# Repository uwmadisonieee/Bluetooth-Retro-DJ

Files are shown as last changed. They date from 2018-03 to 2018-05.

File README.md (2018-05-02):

# Bluetooth Retro DJ

This is a IEEE project designed to grab all the attention at every table event. Using the power of ECE majors we contructed the ultimate Retro DJ set that communicates between bluetooth.

<p align="center">
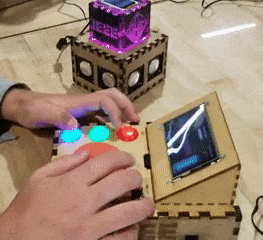
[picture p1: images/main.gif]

</p>

## How It All Works!

For details on this, check out either the [Medium Article](https://medium.com/@spencerfricke/bluetooth-dj-set-diy-embedded-systems-d240a5f08773), [short YouTube Video of it](https://youtu.be/4wVTRmy3RTk), or feel free to glance around the code.

## MIDI Controller Box

<p align="center">
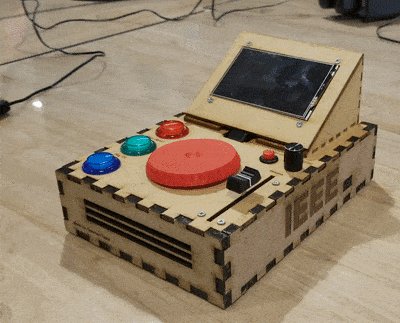
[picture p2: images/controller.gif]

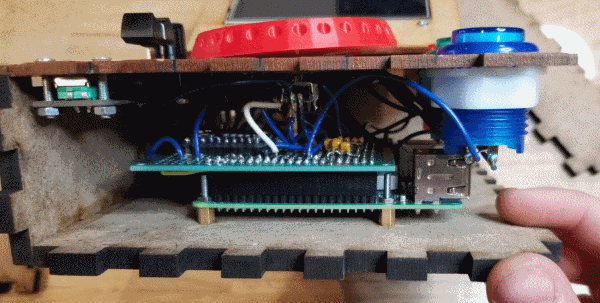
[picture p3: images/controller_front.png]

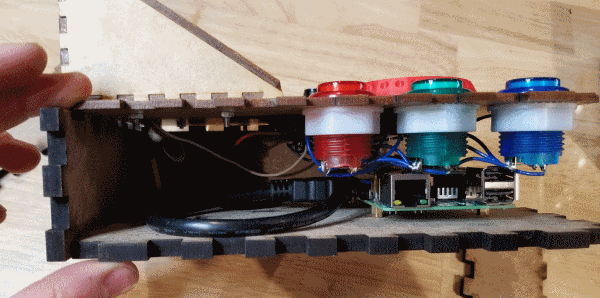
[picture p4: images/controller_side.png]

</p>

## LED Speaker

<p align="center">
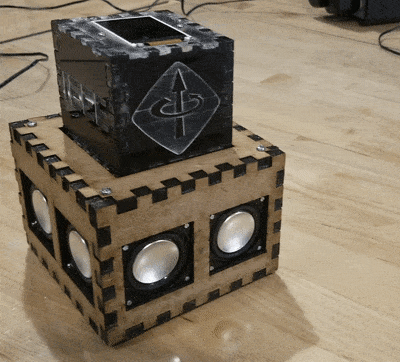
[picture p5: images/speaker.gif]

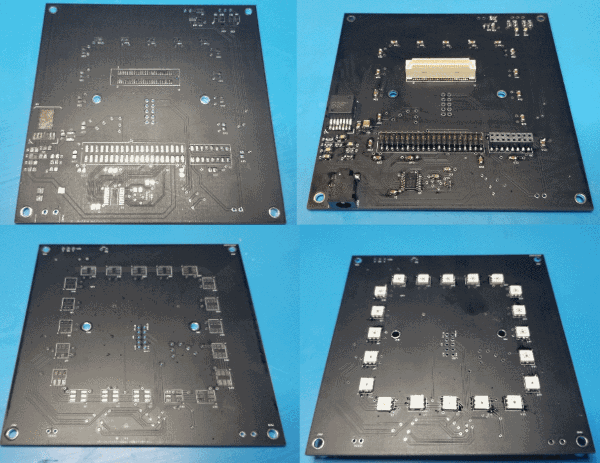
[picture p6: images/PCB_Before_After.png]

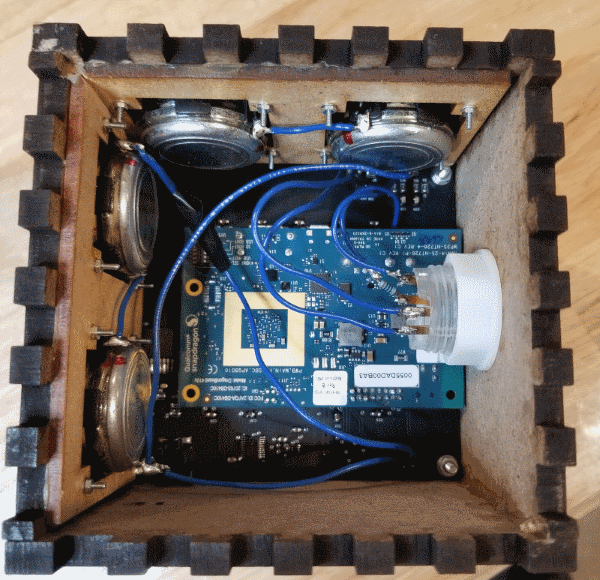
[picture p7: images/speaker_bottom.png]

</p>

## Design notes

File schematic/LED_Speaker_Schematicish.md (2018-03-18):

# LED Speaker Schematics*ish*

> "Sorry Max, I should have learned how to use Altium" ~ Spencer 2018

**Table of Contents**

- [PCB](#pcb)
  - [Basic Layout Concept](#basic-layout-concept)
  - [Dragonboard](#dragonboard)
  - [Power](#power)
  - [Standoff Holes](#standoff-holes)
- [Dragonboard GPIO](#dragonboard-gpio)
- [APA102 LEDS](#apa102-leds)
  - [Layout](#layout)
  - [Pins](#pins)
- [LCD Screen](#lcd-screen)
  - [Pins needed](#pins-needed)
- [Rotary Encoder and Button](#rotary-encoder-and-button)
- [Speakers](#speakers)

# PCB

**Dimensions:** 100mm x 100mm

[Blender File](https://github.com/uwmadisonieee/Bluetooth-Retro-DJ/raw/master/3D_Models/LED_Speaker/LED_Speaker.blend)

## Basic Layout Concept
- 20 LEDs
- Standoffs for inside and out for structural support
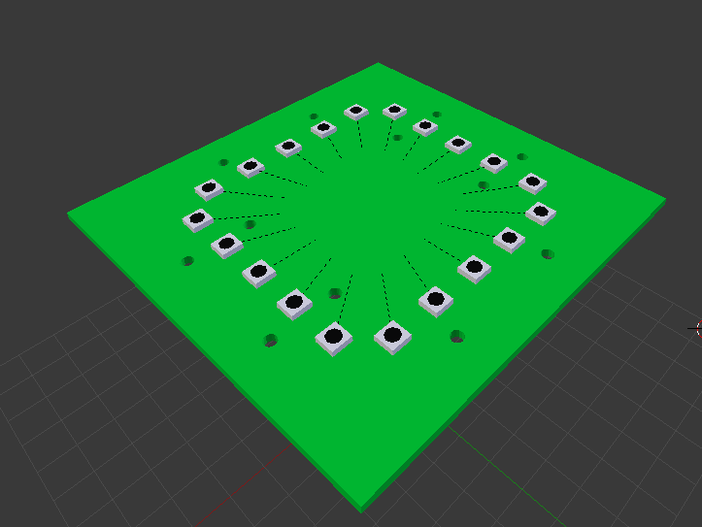
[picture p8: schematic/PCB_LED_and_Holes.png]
- 

## Dragonboard
- Attached from under via Low and High speed connectors (same as Truman)
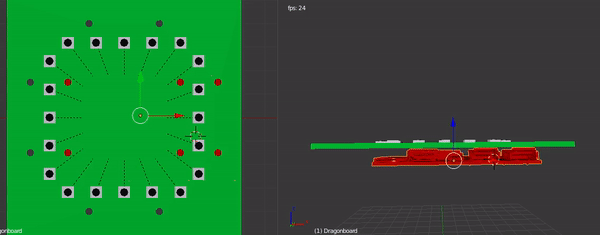
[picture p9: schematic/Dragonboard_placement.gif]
- 
- 
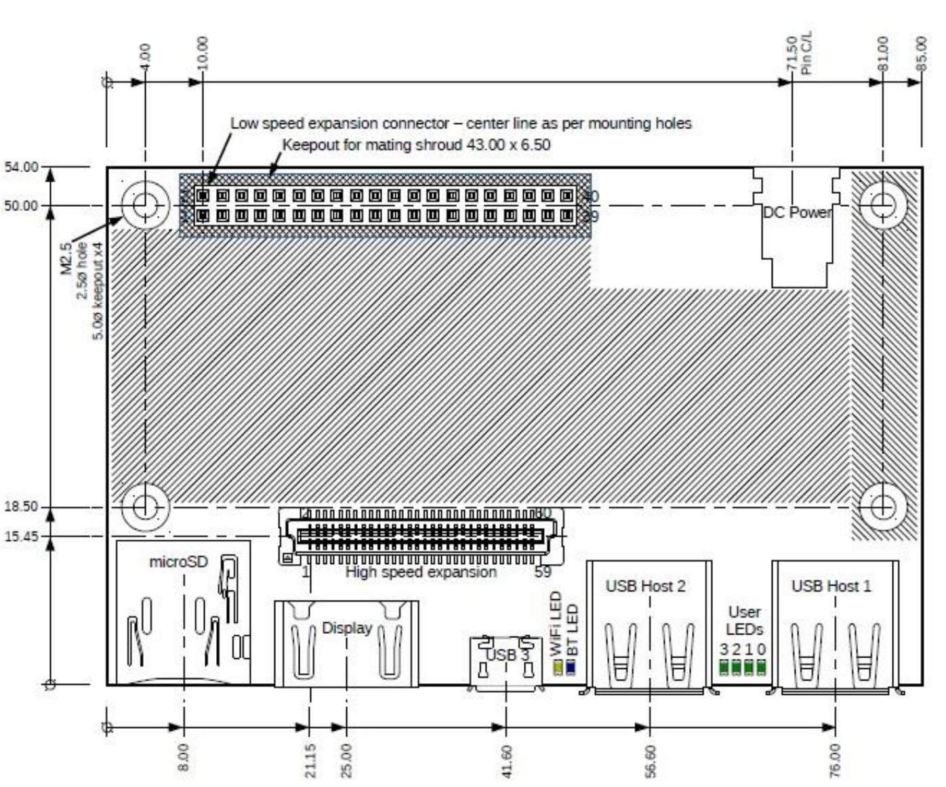
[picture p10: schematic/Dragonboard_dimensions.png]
- 
	
## Power

- Barrel Jack on edge of PCB
	- On bottom side
	- Which side is not a concern
- EIAJ3 plug which has 4.75mm diameter with 1.7mm inner diameter
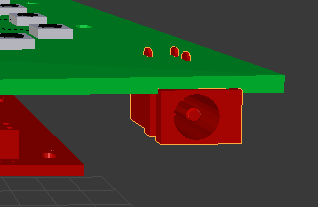
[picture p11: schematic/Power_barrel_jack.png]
- 

## Standoff Holes
- All Standoff holes are M3 so 3mm diameter holes
- I need to mount the PCB to the base wood box with the outer holes
	- These honestly can be **anywhere**, the closer to the edge would be best for structural support I think
- The inner standoffs are going to be mounted to a pole mounted to top cube
	- These need to be a little more aimed because there is a LED screen on top
	- There is a **12.325mm x 58.65mm** box on each side for two standoff holes
- 

# Dragonboard GPIO
- [Hardware Docs](https://github.com/96boards/documentation/tree/master/consumer/dragonboard410c/hardware-docs)
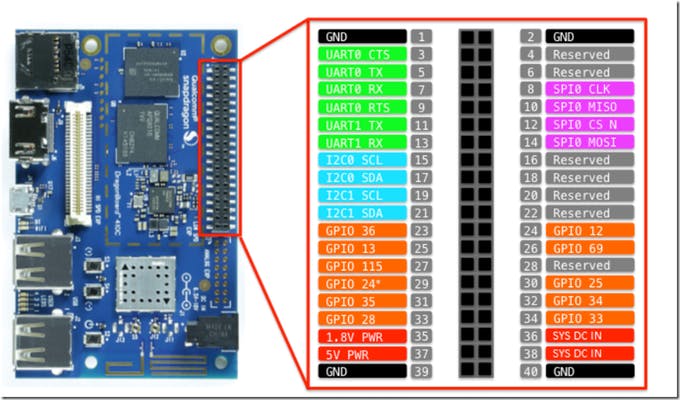
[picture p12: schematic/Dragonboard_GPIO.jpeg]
- 
- **PIN 8** - SPI Clk for LED and LCD
- **PIN 14** - SPI MOSI for LED and LCD
- **PIN 24** - SPI Clock Select pin to control Mux for LED and LCD
	- **LOW** turns on LCD
	- **HIGH** turns on LED
- **PIN 26** - Reset Pin for LCD 
- **PIN 31** - Data/Control pin for LCD
- **PIN 32** - Rotary Encoder A
- **PIN 34** - Rotary Encoder B
- **PIN 33** - Push Button

# APA102 LEDS
- [Datasheet](https://cdn.sparkfun.com/datasheets/Components/LED/APA102C.pdf)
- 5mm x 5mm x 1.4mm 
	- [8 long example datasheet](https://cdn.sparkfun.com/assets/d/e/9/0/e/Lumenati_8-stick.pdf) 
		- [Eagle Files](https://github.com/sparkfun/Lumenati_8-Stick/tree/master/Hardware)
	- [1 meter strip example datasheet](https://cdn.sparkfun.com/datasheets/Components/LED/S60102.pdf) 

- 20 LEDs on PCB all in series
- Draws ~1.92A at full white light

## Layout
- 
- All LEDs in each strip are 31.825mm from center in X or Y direction
- All LEDs are 18.175mm from edge
- Each LED is 12mm apart from center to center
	- This starts with the middle LED at center in row

## Pins
- Each has 6 pins
	- Data In
	- Clock In
	- GND
	- Data Out
	- Clock Out
	- VCC
- **VCC and GND**
	- This is ran on a 5V rail from main power source because LEDs current draw too much for Dragonboard
- **Data In**
	- The first LED in series is sent data from **PIN 14** of Dragonboard **stepped up to 5V**
- **Clock In**
	- The first LED in series is sent clock from **PIN 8** of Dragonboard **stepped up to 5V**	
- **Clock Select**
	- The first LED in series is clock select via a mux on PCB from **PIN 24** of Dragonboard
	- The APA102 LED only takes SPI feed and has be muxed so SPI can be used in LCD screen as well

# LCD Screen
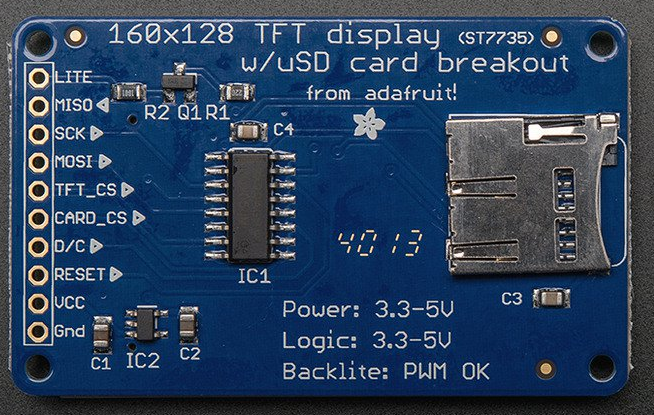
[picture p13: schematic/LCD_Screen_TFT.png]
- 
- This screen will be on top of cube so through holes needed to soilder wires
	- **DONT WORRY** Inside of acrylic is going to be painted black so no one will see wires
- All pins **stepped up to 5V**
- Holes must be in inner part of LED ring

## Pins needed
- **LITE and VCC** - This is a 5V power line
- **GND**
- **SCK** --- **PIN 8** of Dragonboard for SPI CLK
- **MOSI** --- **PIN 14** of Dragonboard for SPI MOSI
- **RESET** --- **PIN 28** of Dragonboard
- **D/C** (Data/Control) --- **PIN 30** of Dragonboard
- **TFT_CS** --- **PIN 24** of Dragonboard is used to toggle between LED and LCD screen, this is the pin to toggle for LCD Screen

# Rotary Encoder and Button
- I am going to have these coming out from a side of speaker box
- Need through hole of **PIN 32**, **PIN 33**, and **PIN 34** for controlling these
- Not same side as power barell jack
- Holes will need to be accessed from bottom so best to use edge where Dragonboard isn't sticking out

# Speakers
- We **only need the 2** pins on the edge nearest to the 40 pin set (pin 1 and 2)
	- I will need 2 through hole pins to wire up the Speakers underneath
	- Same idea as Encoder and Button where to put near on a side where Dragonboard isn't sticking out
- [Datasheet for Dragonboard Audio](https://developer.qualcomm.com/qfile/29468/lm80-p0436-43_stereocontaudioroutappnote.pdf)
- What the Audio Mezz does
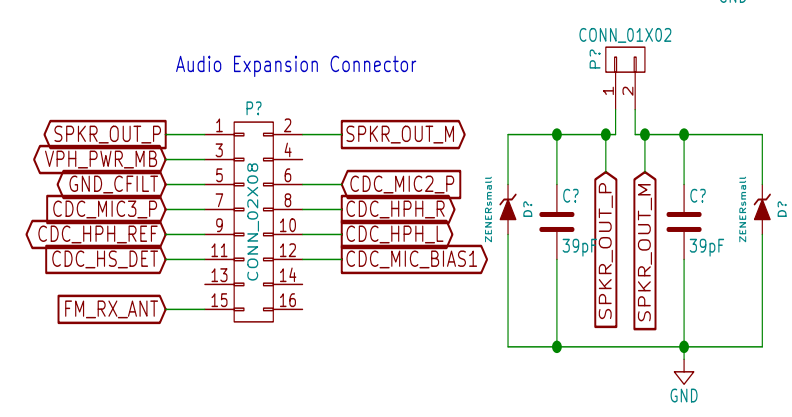
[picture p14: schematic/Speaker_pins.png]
	- 
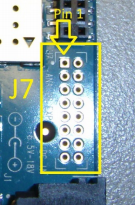
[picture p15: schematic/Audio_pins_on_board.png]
- 
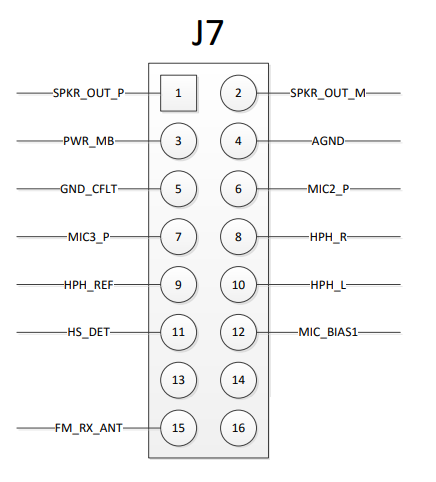
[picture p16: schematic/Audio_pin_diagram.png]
-

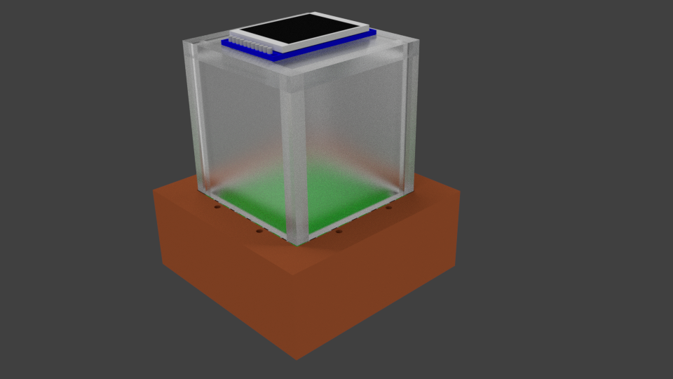
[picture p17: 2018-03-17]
3D_Models/LED_Speaker/LED_Concept.png

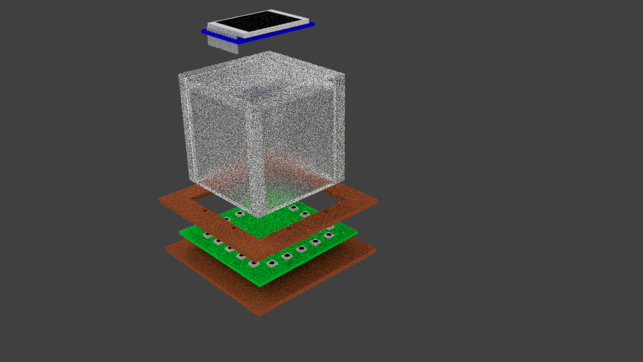
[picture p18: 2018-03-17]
3D_Models/LED_Speaker/LED_Concept_stretched.png

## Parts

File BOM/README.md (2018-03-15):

# Bill of materials

This isn't a true BOM, but more of a checklist that I order everything I need for this project

- [MIDI Controller Box](MIDI_Controller_Box_BOM.md)

- [LED Speaker](LED_Speaker_BOM.md)

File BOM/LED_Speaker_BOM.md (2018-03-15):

# LED Speaker BOM

- Dragonboard
- 128x160 TFT LED Screen
- Custon PCB with LEDs on it
- Rotatry Encoder
- Button
- Set of Speakers
- Protoboard
- Standoffs
- 3.3v to 5v chips
- PCB design
	- TBD

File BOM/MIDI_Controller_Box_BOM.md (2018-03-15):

# MIDI Controller Box BOM

- Pi
- rotary encoder
- 3D printed jog wheel
- potentiometer slider
- (3) LED arcade buttons
- (2) dial potentiometer
- 4 inch HDMI screen
- HDMI cable (short)
- Protoboard
- Standoffs
- microUSB outlet to wires
- ADC Module
- 3.3v to 5v chips

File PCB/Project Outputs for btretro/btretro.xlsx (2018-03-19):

Comment | Description | Designator | LibRef | Manufacturer 1 | Quantity | Supplier 1 | Supplier Part Number 1
CAP_0805_.1u_250V | Cap Ceramic 0.1uF 250V X7T 10% SMD 0805 125C Plastic T/R | C1, C2, C11, C12, C13, C14, C15, C16, C17, C18, C19, C20, C21, C22, C23, C24, C25, C26, C27, C28, C29, C30, C31 | CAP_0805_.1u_250V | TDK | 23 | Digi-Key | 445-8883-1-ND
CAP_0805_m22n | CAP CER 0.022UF 100V X7R 0805 | C5, C10 | CAP_0805_22n_100V | TDK | 2 | Digi-Key | 445-9184-1-ND
CAP_0805_10u_16V | Cap Ceramic 10uF 16V X5R 10% SMD 0805 85C T/R | C6 | CAP_0805_10u_16V | Johanson | 1 | Digi-Key | 709-1229-1-ND
CAP_1210_100u_10V | Cap Ceramic 100uF 10V X5R 20% SMD 1210 85C Embossed T/R | C7 | CAP_1210_100u_10V | Murata | 1 | Digi-Key | 490-9969-1-ND
CAP_0805_1u_100V | CAP CER 1UF 100V X7S 0805 | C8 | CAP_0805_1u_100V | TDK | 1 | Digi-Key | 445-8887-1-ND
CAP_0805_22u_25V | 22µF ±20% 25V X5R Ceramic Capacitor -55°C ~ 85°C Surface Mount, MLCC 0805 (2012 Metric) 0.079" L x 0.049" W (2.00mm x 1.25mm) | C9 | CAP_0805_22u_25V | Samsung | 1 | Digi-Key | 1276-2908-1-ND
CAP_0805_10n_250V | Cap Ceramic 0.1uF 250V X7T 10% SMD 0805 125C Plastic T/R | C32, C33 | CAP_0805_10n_250V | TDK | 2 | Digi-Key | 445-2280-1-ND
DragonBoard_HIGH_SPEED | 60 Position Connector Plug, Center Strip Contacts Surface Mount Gold | J1 | DragonBoard_HIGH_SPEED | Amphenol FCI | 1 | Digi-Key | 609-1681-1-ND
DragonBoard_LOW_SPEED | 40 Positions Header, Unshrouded Connector 0.079" (2.00mm) Surface Mount Gold, GXT™ | J2 | DragonBoard_LOW_SPEED | Amphenol FCI | 1 | Digi-Key | 609-2632-ND
DragonBoard_ANALOG | Conn Socket Strip RCP 16 POS 2mm Solder ST SMD Tube | J3 | DragonBoard_ANALOG | Molex | 1 | Digi-Key | WM18703-ND
Display | TFT Display | LCD1 | LCD_SCREEN_BTRETRO |  | 1
MOUNTHOLES | HOLE | MH1, MH2, MH5, MH6, MH7, MH8 | MOUNTHOLES |  | 6
EIAJ3 | PJ1-021 Series 1.65 mm x 5.15 mm 16 V Right Angle SMT Power Jack | PWR1 | EIAJ3 | CUI | 1 | Digi-Key | CP1-021PJCT-ND
RES_5.23K | Thick Film Resistors 5.23K OHM 1% | R2 | RES_0805_5.23K | Yageo | 1 | Digi-Key | 311-5.23KCRCT-ND
RES_0805_1K | RES SMD 1K OHM 1% 1/8W 0805 | R3 | RES_0805_1K | Yageo Phycomp | 1 | Digi-Key | 311-1.00KCRCT-ND
RES_0805_23.2K | RESISTOR, THICK FILM, 23.2KOHM, 125mW, ± 1% | R4 | RES_0805_23.2K | Panasonic ECG | 1 | Digi-Key | P23.2KCCT-ND
RES_0805_100K | Res Thick Film 0805 100K Ohm 1% 0.125W(1/8W) ±100ppm/C Molded SMD Automotive Punched T/R | R5 | RES_0805_100K | Panasonic ECG | 1 | Digi-Key | P100KCCT-ND
RES_0805_11.8K | RES SMD 11.8K OHM 1% 1/8W 0805 | R6 | RES_0805_11.8K | Yageo | 1 | Digi-Key | 311-11.8KCRCT-ND
RES_0805_10K | RES, THICK FILM, 10K, 5%, 0.125W, 0805 | R7, R8, R9, R10, R11 | RES_0805_10K | Yageo | 5 | Digi-Key | 311-10KARCT-ND
ROT_ENCODER | Encoders 15mm SHAFT w/SWITCH | ROT1 | ROT_ENCODER | Bourns | 1 | Digi-Key | PEC11R-4015F-S0024-ND
CDS-27204-L100 | 4 Ohm Magnetic Speaker 2W 20Hz ~ 20kHz Top Rectangular 93dB | SPKR1 | CDS-27204-L100 | CUI (https://octopart-clicks.com/click/altium?sku=277-1667-ND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) | 1 | Digi-Key | 102-3547-ND (https://octopart-clicks.com/click/altium?sku=277-1667-ND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)
BUTTON | ...It's a button! | SW1 | BUTTON |  | 1
TXS0108 | TRANSLATOR, VOLTAGE, 8BIT, 20TSSOP | U1 | TXS0108 | Texas Instruments | 1 | Digi-Key | 296-23011-1-ND
LMZ12003 | POWER MODULE, TO-PMOD-7, FULL REEL | U2 | LMZ12003 | TI National Semiconductor | 1 | Digi-Key | LMZ12003TZ-ADJ/NOPBCT-ND
APA102c | SPI LED | U3, U4, U5, U6, U7, U8, U9, U10, U11, U12, U13, U14, U15, U16, U17, U18, U19, U20, U21, U22 | APA102 |  | 20
SN74LVC1G17 | IC BUFFER SCHMIT TRIG SOT23-5 | U23 | SN74LVC1G17 | Texas Instruments | 1 | Digi-Key | 296-11933-1-ND
NC7SZ167 | FAIRCHILD SEMICONDUCTOR NC7SZ157P6X Logic Type:Multiplexer | U24 | NC7SZ157 | ON Semiconductor | 1 | Digi-Key | NC7SZ157P6XCT-ND

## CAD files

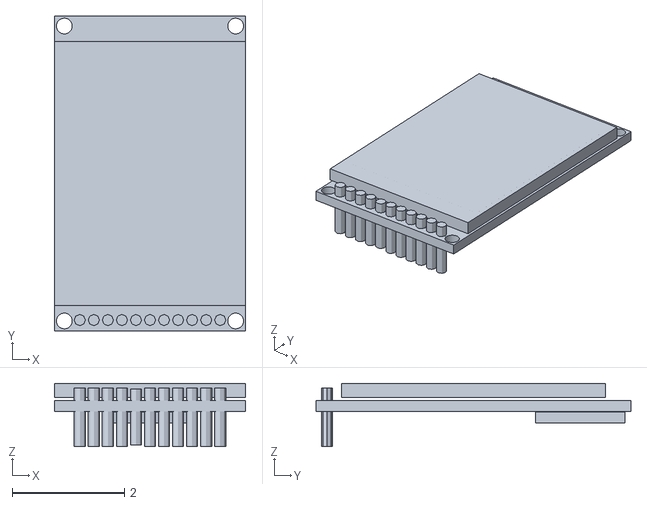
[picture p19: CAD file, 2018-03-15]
3D_Models/LED_Speaker/1-8inch_TFT_Color_LCD.stl
3.40 x 5.60 x 1.13

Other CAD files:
3D_Models/LED_Speaker/1-8inch_TFT_Color_LCD.blend
3D_Models/MIDI_Controller_Box/Controller_Box.blend

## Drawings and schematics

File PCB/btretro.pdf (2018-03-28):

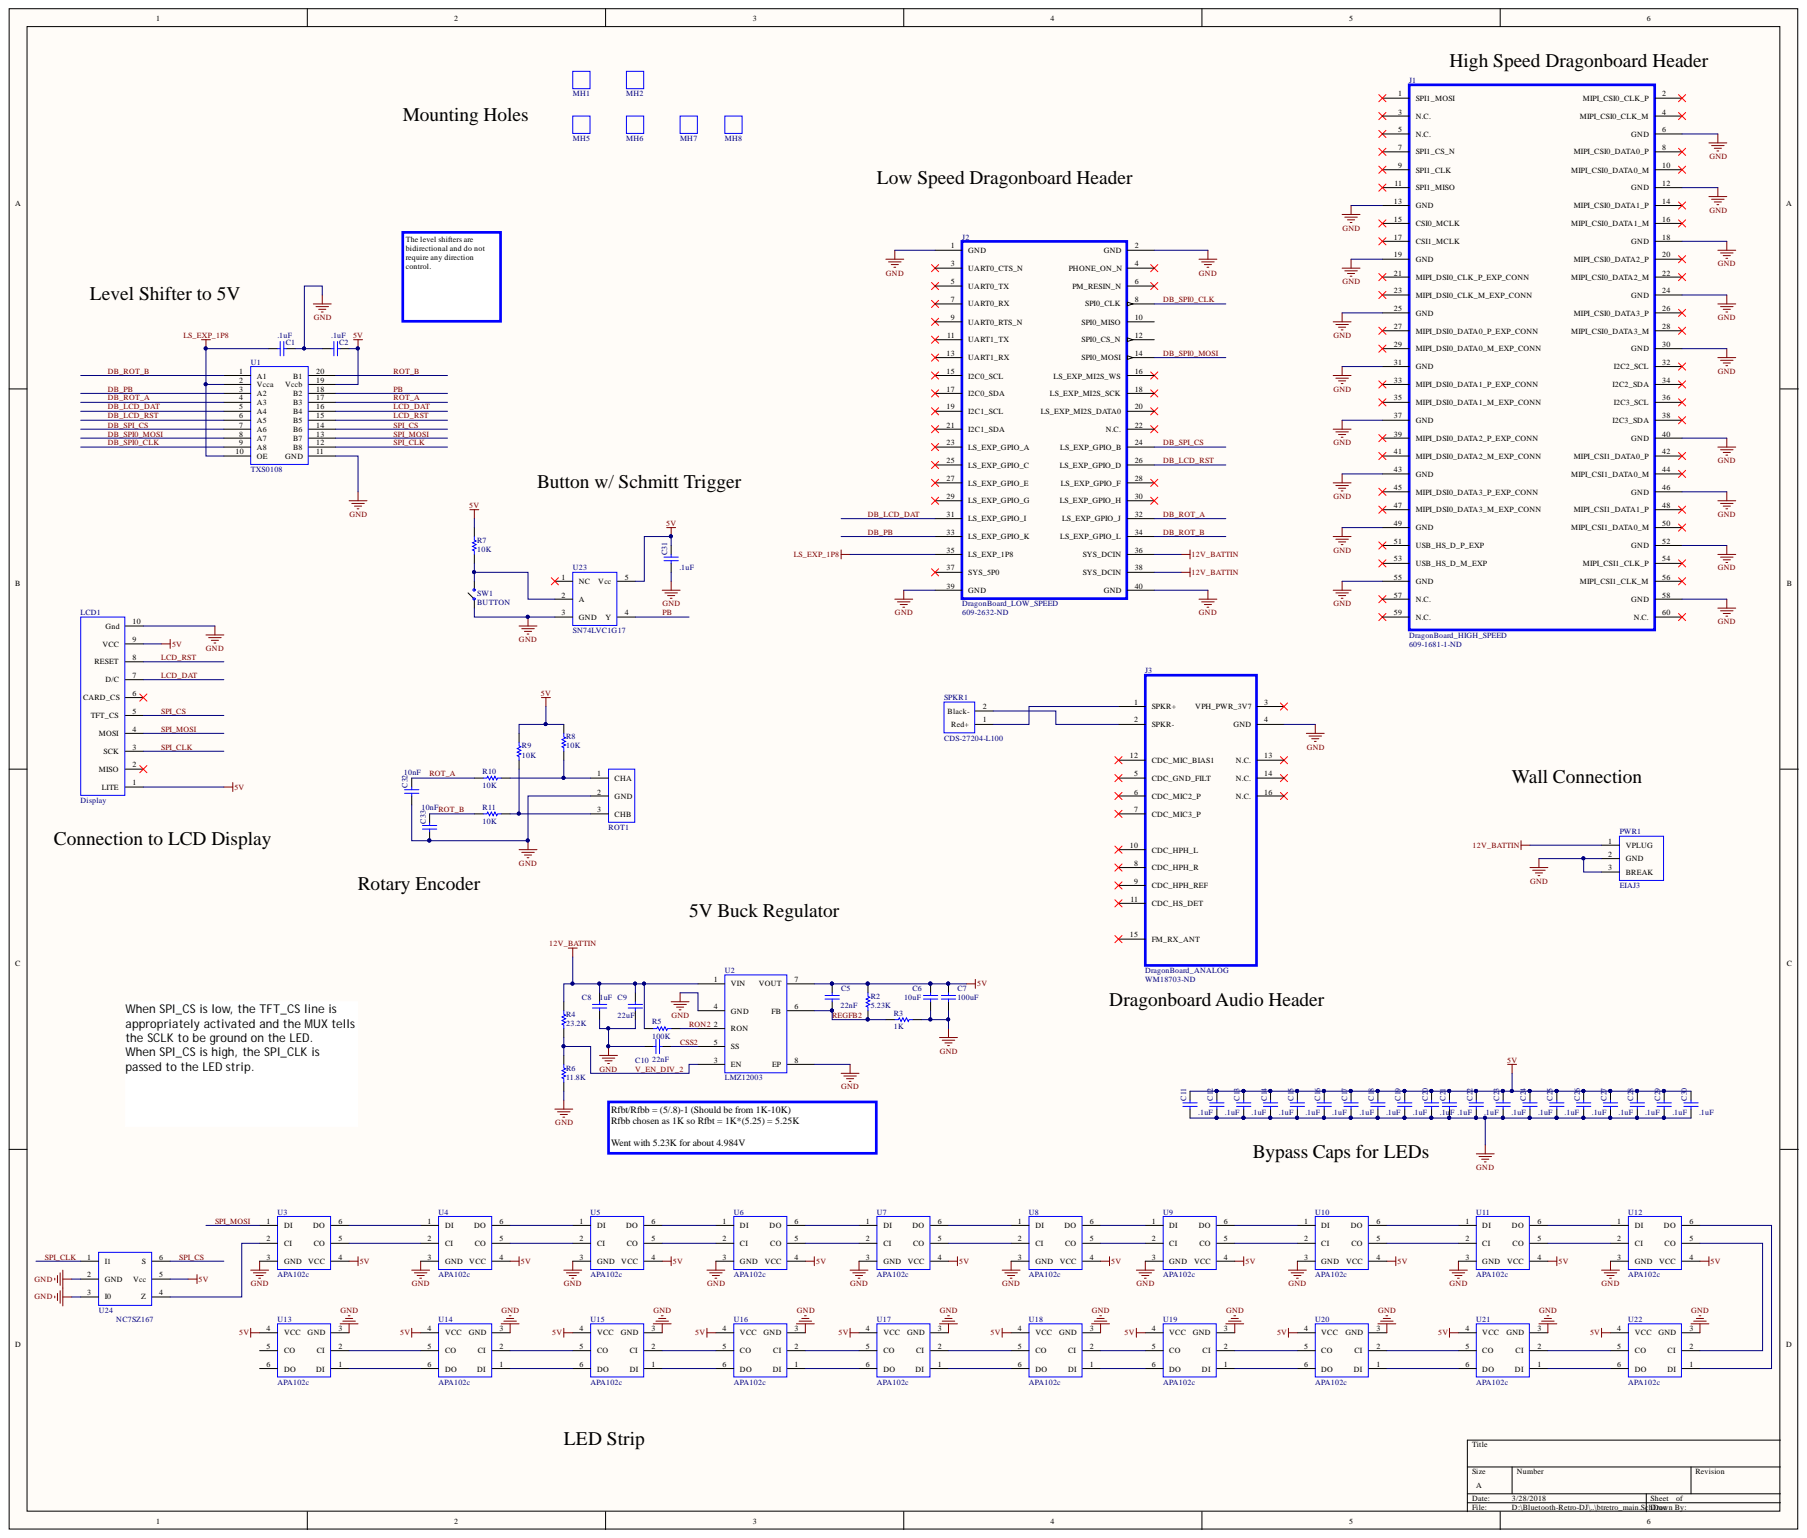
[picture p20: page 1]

High Speed Dragonboard Header

Low Speed Dragonboard Header

The level shifters are
bidirectional and do not
require any direction
control.

Connection to LCD Display

When SPI_CS is low, the TFT_CS line is
appropriately activated and the MUX tells
the SCLK to be ground on the LED.
When SPI_CS is high, the SPI_CLK is
passed to the LED strip.

Rfbt/Rfbb = (5/.8)-1 (Should be from 1K-10K)
Rfbb chosen as 1K so Rfbt = 1K*(5.25) = 5.25K

Went with 5.23K for about 4.984V

Bypass Caps for LEDs

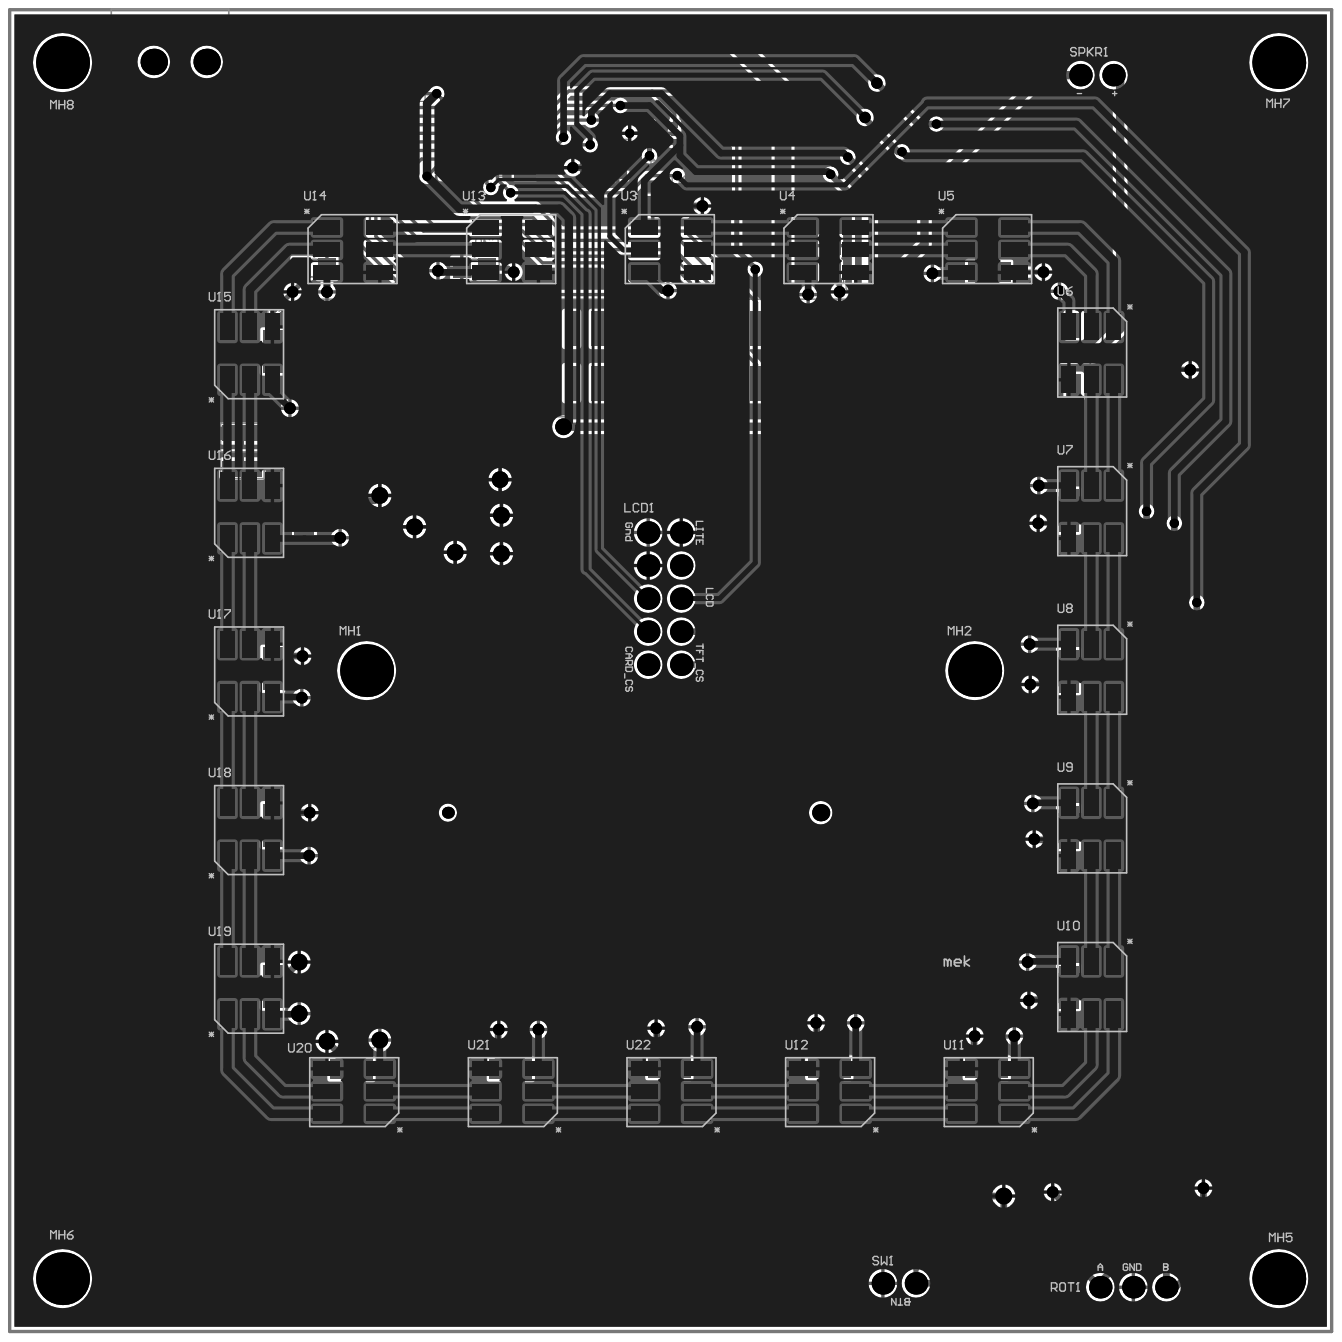
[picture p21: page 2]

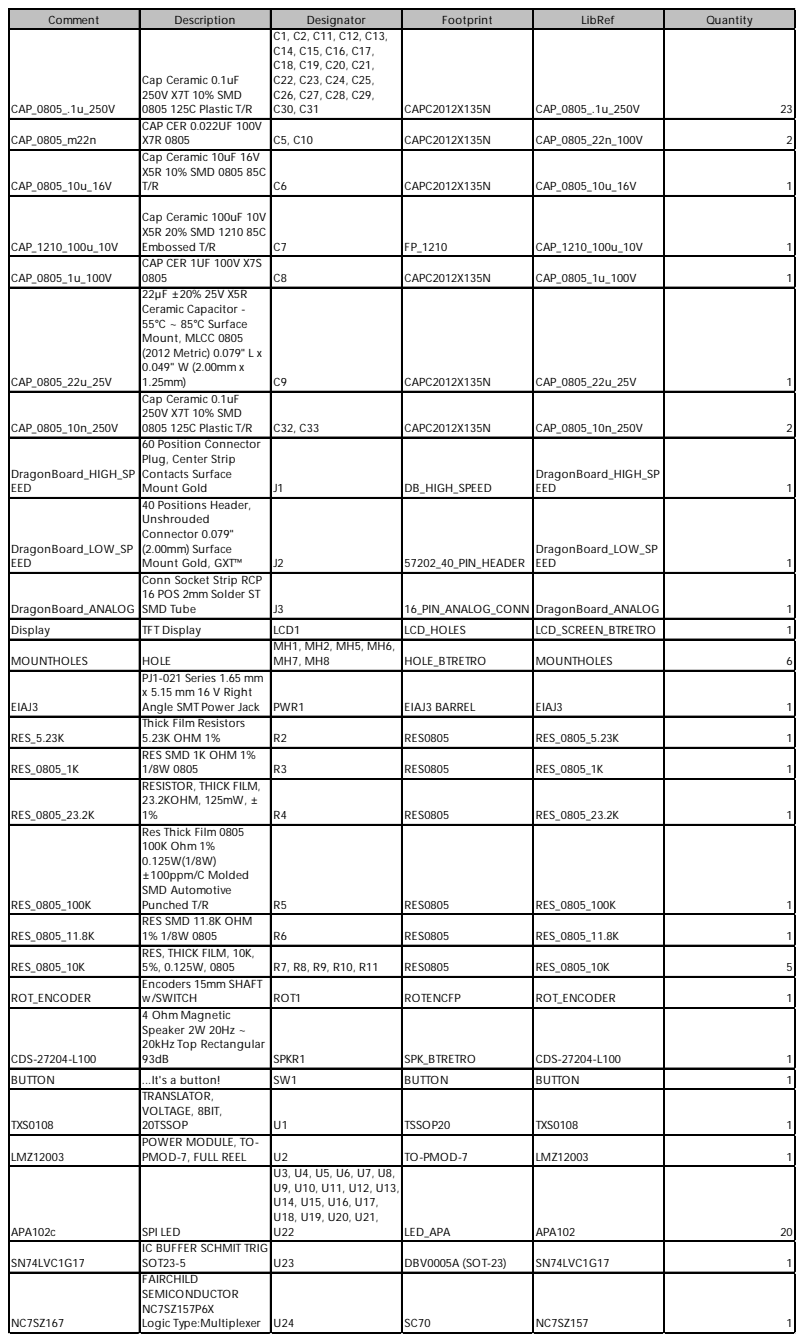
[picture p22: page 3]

Comment | Description | Designator | Footprint | LibRef | Quantity

CAP_0805_.1u_250V | Cap Ceramic 0.1uF 250V X7T 10% SMD 0805 125C Plastic T/R | C1, C2, C11, C12, C13, C14, C15, C16, C17, C18, C19, C20, C21, C22, C23, C24, C25, C26, C27, C28, C29, C30, C31 | CAPC2012X135N | CAP_0805_.1u_250V | 23

CAP_0805_m22n | CAP CER 0.022UF 100V X7R 0805 | C5, C10 | CAPC2012X135N | CAP_0805_22n_100V | 2

CAP_0805_10u_16V | Cap Ceramic 10uF 16V X5R 10% SMD 0805 85C T/R | C6 | CAPC2012X135N | CAP_0805_10u_16V | 1

CAP_1210_100u_10V | Cap Ceramic 100uF 10V X5R 20% SMD 1210 85C Embossed T/R | C7 | FP_1210 | CAP_1210_100u_10V | 1

CAP_0805_1u_100V | CAP CER 1UF 100V X7S 0805 | C8 | CAPC2012X135N | CAP_0805_1u_100V | 1

CAP_0805_22u_25V | 22µF ±20% 25V X5R Ceramic Capacitor -55°C ~ 85°C Surface Mount, MLCC 0805 (2012 Metric) 0.079" L x 0.049" W (2.00mm x 1.25mm) | C9 | CAPC2012X135N | CAP_0805_22u_25V | 1

CAP_0805_10n_250V | Cap Ceramic 0.1uF 250V X7T 10% SMD 0805 125C Plastic T/R | C32, C33 | CAPC2012X135N | CAP_0805_10n_250V | 2

DragonBoard_HIGH_SP EED | 60 Position Connector Plug, Center Strip Contacts Surface Mount Gold | J1 | DB_HIGH_SPEED | DragonBoard_HIGH_SP EED | 1

DragonBoard_LOW_SP EED | 40 Positions Header, Unshrouded Connector 0.079" (2.00mm) Surface Mount Gold, GXT™ | J2 | 57202_40_PIN_HEADER | DragonBoard_LOW_SP EED | 1

DragonBoard_ANALOG | Conn Socket Strip RCP 16 POS 2mm Solder ST SMD Tube | J3 | 16_PIN_ANALOG_CONN | DragonBoard_ANALOG | 1

Display | TFT Display | LCD1 | LCD_HOLES | LCD_SCREEN_BTRETRO | 1
MOUNTHOLES | HOLE | MH1, MH2, MH5, MH6, MH7, MH8 | HOLE_BTRETRO | MOUNTHOLES | 6

EIAJ3 | PJ1-021 Series 1.65 mm x 5.15 mm 16 V Right Angle SMT Power Jack | PWR1 | EIAJ3 BARREL | EIAJ3 | 1

RES_5.23K | Thick Film Resistors 5.23K OHM 1% | R2 | RES0805 | RES_0805_5.23K | 1

RES_0805_1K | RES SMD 1K OHM 1% 1/8W 0805 | R3 | RES0805 | RES_0805_1K | 1

RES_0805_23.2K | RESISTOR, THICK FILM, 23.2KOHM, 125mW, ± 1% | R4 | RES0805 | RES_0805_23.2K | 1

RES_0805_100K | Res Thick Film 0805 100K Ohm 1% 0.125W(1/8W) ±100ppm/C Molded SMD Automotive Punched T/R | R5 | RES0805 | RES_0805_100K | 1

RES_0805_11.8K | RES SMD 11.8K OHM 1% 1/8W 0805 | R6 | RES0805 | RES_0805_11.8K | 1

RES_0805_10K | RES, THICK FILM, 10K, 5%, 0.125W, 0805 | R7, R8, R9, R10, R11 | RES0805 | RES_0805_10K | 5

ROT_ENCODER | Encoders 15mm SHAFT w/SWITCH | ROT1 | ROTENCFP | ROT_ENCODER | 1

CDS-27204-L100 | 4 Ohm Magnetic Speaker 2W 20Hz ~ 20kHz Top Rectangular 93dB | SPKR1 | SPK_BTRETRO | CDS-27204-L100 | 1

BUTTON | ...It's a button! | SW1 | BUTTON | BUTTON | 1
TXS0108 | TRANSLATOR, VOLTAGE, 8BIT, 20TSSOP | U1 | TSSOP20 | TXS0108 | 1

LMZ12003 | POWER MODULE, TO-PMOD-7, FULL REEL | U2 | TO-PMOD-7 | LMZ12003 | 1

APA102c | SPI LED | U3, U4, U5, U6, U7, U8, U9, U10, U11, U12, U13, U14, U15, U16, U17, U18, U19, U20, U21, U22 | LED_APA | APA102 | 20

SN74LVC1G17 | IC BUFFER SCHMIT TRIG SOT23-5 | U23 | DBV0005A (SOT-23) | SN74LVC1G17 | 1

NC7SZ167 | FAIRCHILD SEMICONDUCTOR NC7SZ157P6X Logic Type:Multiplexer | U24 | SC70 | NC7SZ157 | 1

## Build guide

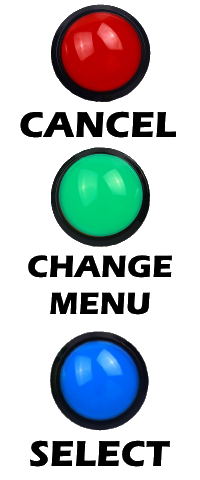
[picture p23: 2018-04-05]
code/MIDI_Controller_Box/website/css/instructions.png

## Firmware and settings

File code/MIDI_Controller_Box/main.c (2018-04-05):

#include "main.h"
#include <ads1115.h>

extern server_t* g_server;
int server_connected = 0;

void WebDataCallback(int type, char* value) {

  switch(type) {
  case 0:
    server_connected = 1;
    break;
  case 1:
    BlueMessage(0, value);
    break;
  case 2:
    BlueMessageInt(2, play_pause);
  case 3:
    BlueMessage(3, value);
    break;
  case 4:
    fprintf(stdout, "Song Select: %s\n", value);
    BlueMessage(4, value);
    break;
  case 5:
    fprintf(stdout, "Sample Select: %s\n", value);
    BlueMessage(5, value);
    break;
  case 6:
    BlueMessage(6, value);
    break;
  default:
    fprintf(stderr, "Not a valid type [%d]\n", type);
    break;
  }
}

void BlueDataInit(char* value) {
  //  const char s[2] = ";";
  //  char *token;
  //  char send_buffer[4096];

  //  token = strtok(value, s);
  //  while (token != NULL) {

    broadcastString("0", value);
    fprintf(stdout, "\n\n%s\n\nbluedatainit done\n", value);
    //    token = strtok(NULL, s);
    //  }

}

void BlueDataAnalysis(char* value) {
  fprintf(stdout, "bluedataAnalysis\n");
  broadcastString("1", value);
  fprintf(stdout, "bluedataAnalysis done\n");
}

void BlueDataCallback(int type, char* value) {
  
  switch(type) {
  case 0:
    break;
  case 1:
    fprintf(stdout, "\n\n%s\n\n", value);
    broadcastString("1", value);
    break;
  default:
    fprintf(stderr, "Not a valid type [%d]\n", type);
    break;
  }  
}

static unsigned long l_red_irq = 0;
static unsigned long c_red_irq = 0;
static unsigned long l_green_irq = 0;
static unsigned long c_green_irq = 0;
static unsigned long l_blue_irq = 0;
static unsigned long c_blue_irq = 0;
static unsigned long l_gif_irq = 0;
static unsigned long c_gif_irq = 0;

void RedButton(void) {
  c_red_irq = millis();
  if (c_red_irq - l_red_irq > 20) {
    play_pause ^= 1;
    broadcastInt("2", play_pause);
  }
  l_red_irq = c_red_irq;
}
void GreenButton(void) {
  c_green_irq = millis();
  if (c_green_irq - l_green_irq > 20) {
    broadcastInt("3", 0);
  }
  l_green_irq = c_green_irq;
}
void BlueButton(void) {
  c_blue_irq = millis();
  if (c_blue_irq - l_blue_irq > 20) {
    broadcastInt("4", 0);
  }
  l_blue_irq = c_blue_irq;
}
void GifButton(void) {
  c_gif_irq = millis();
  if (c_gif_irq - l_gif_irq > 20) {
   BlueMessage(8, "-");
  }
  l_gif_irq = c_gif_irq;
}

pthread_t rotary_thread;
void* rotaryDeal(void* na)
{
  unsigned char flag;
  unsigned char Last_RoB_Status;
  unsigned char Current_RoB_Status;

  while(1) {
    Last_RoB_Status = digitalRead(JOG_DATA_B);
    
    while(!digitalRead(JOG_DATA_A)){
      Current_RoB_Status = digitalRead(JOG_DATA_B);
      flag = 1;
    }
    
    if(flag == 1){
      flag = 0;
      if((Last_RoB_Status == 0)&&(Current_RoB_Status == 1)){
	broadcastInt("5", 1);
	//fprintf(stdout, "ROTARY ++\n");
      }
      if((Last_RoB_Status == 1)&&(Current_RoB_Status == 0)){
	broadcastInt("5", -1);
	//fprintf(stdout, "ROTARY --\n");
      }

    }
  }
}

static int last_slider;
static int last_pot;
static int slider_v;
static int pot_v;

void HardwareSetup() {
  if (wiringPiSetupGpio() < 0) {
    fprintf(stderr, "Failed to start wiringP\n");
    exit(-1);
  }

  pinMode(BLUE_BUT, INPUT);
  pinMode(GREEN_BUT, INPUT);
  pinMode(RED_BUT, INPUT);
  pinMode(GIF_BUT, INPUT);

  wiringPiISR (BLUE_BUT, INT_EDGE_FALLING, &BlueButton);
  wiringPiISR (GREEN_BUT, INT_EDGE_FALLING, &GreenButton);
  wiringPiISR (RED_BUT, INT_EDGE_FALLING, &RedButton);
  wiringPiISR (GIF_BUT, INT_EDGE_FALLING, &GifButton);

  pinMode(JOG_DATA_A, INPUT);
  pinMode(JOG_DATA_B, INPUT);

  pullUpDnControl(JOG_DATA_A, PUD_UP);
  pullUpDnControl(JOG_DATA_B, PUD_UP);

  ads1115Setup (ADC_BASE, 0x48);

  last_slider = analogRead (ADC_BASE + SLIDER_BASE) / SLIDER_DIV;
  last_pot = analogRead (ADC_BASE + POT_BASE) / POT_DIV;
}

int main(int argc, char* argv[]) {
  int status;
  char val[16];
  
  HardwareSetup();
  /*
    while(1){
     slider_v = analogRead (ADC_BASE + SLIDER_BASE) / SLIDER_DIV;;
      pot_v = analogRead (ADC_BASE + POT_BASE) / POT_DIV;
      //      printf("TEST: S: %d\tP: %d\n", slider_v, pot_v); usleep(100000); continue;
      rotaryDeal();
      //usleep(500000);
      }*/
  status = pthread_create(&rotary_thread, NULL, rotaryDeal, NULL);
  g_server = (server_t*)malloc(sizeof(server_t));
  g_server->port = 6419;
  g_server->onSocketMessage = WebDataCallback;

  startServer();

  bluetooth_on_init = BlueDataInit;
  bluetooth_on_analysis = BlueDataAnalysis;
  bluetooth_on_data = BlueDataCallback;

  while(server_connected == 0) {}
  
  BlueStart();
  
  broadcastInt("6", last_slider * 2);
  broadcastInt("7", last_pot * 3);



  if (status < 0) {
    fprintf(stderr, "Failed to start rotary thread");
    exit(-1);
  }
  // main infinite loop
  while(1) {

    // TODO - gets blocked until first jog spin
    slider_v = analogRead (ADC_BASE + SLIDER_BASE) / SLIDER_DIV;
    pot_v = analogRead (ADC_BASE + POT_BASE) / POT_DIV;

    if (slider_v != last_slider) {
      last_slider = slider_v;
      sprintf(val, "%d", slider_v);
      BlueMessage(7, val);
      broadcastInt("6", last_slider * 2);
      //printf("slider: %d\n", slider_v);
    }

    if (pot_v != last_pot) {
      last_pot = pot_v;
      sprintf(val, "%d", pot_v);
      BlueMessage(9, val);
      broadcastInt("7", last_pot * 3);
      //printf("pot: %d\n", pot_v);
    }

    usleep(1000);
    
  }

  return 0;
}

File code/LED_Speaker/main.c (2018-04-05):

#include "main.h"

extern double playback_gain;
extern int lcd_play_next;
extern int lcd_speed;
extern uint8_t spi_lcd_or_led;
void BlueDataCallback( int type, char* value) {
  int val, i;
  double val_d;
  //  FILE *fp;
  fprintf(stdout,"Type: %d\t\tValue: %s\n", type, value);
  switch(type) {
  case 0:
    fprintf(stdout, "message: %s\n", value);
    break;
  case 1:
    break;
  case 2: // play/pause
    val = atoi(value);
    playback_pause = val;
    break;
  case 3: // seek
    val = atoi(value);
    TrackSeek(val);
    break;
  case 4: // new track
    val = atoi(value);
    TrackChange(val);
    ServerMessage(1, tracks[playback_cur_track].analysis);
    break;
  case 5: // new sample
    val = atoi(value);
    playback_cur_sample = val;
    break;
  case 6: // play sample
    playback_play_sample = 1;
    break;
  case 7:
    //between 0 - 50
    val_d = (double)(1.0f * atoi(value)) - 48.0f;
    playback_gain = pow(10.0, val_d / 20.0);
    break;
  case 8:
    lcd_play_next = 1;
  case 9:
    // between 1 - 34
    lcd_speed = ((34-atoi(value)) * 3000) + 10000;
    // get gif speed between 10000 and 100000
    break;
  default:
    fprintf(stderr, "Not a valid type [%d]\n", type);
    break;
  }
}

void* SPILoop(void* na) {

  // LCD will be on majority of time
  while(1) {
    if (spi_lcd_or_led == 0) {
      LCDLoop();
    } else {
      mraa_gpio_write(cs_c, 1); // toggle led

      LEDSend();

      mraa_gpio_write(cs_c, 0); // go back to lcd
      spi_lcd_or_led = 0;
    }
  }
}

void buttonISR(void* arg) {
  led_effect++;

  if (led_effect > LED_MAX_EFFECTS) { led_effect = 0;}

  switch(led_effect) {
  case 0:
    LEDSetAllRed();
    break;
  case 1:
    LEDSetAllGreen();
    break;
  case 2:
    LEDSetAllBlue();
    break;
  }
  
  fprintf(stdout, "pressed : %d\n", led_effect);
}

int main(int argc, char* argv[]) {
  char debug[256];
  int debugI;
  double debugF;
  mraa_gpio_context button;
  int status;
  // need to give data callback
  server_on_data = BlueDataCallback;

  // audio needs to be setup before bluetooth
  PlaybackSetup();
  fprintf(stdout, "Playback Setup\n");

  SPISetup();
  fprintf(stdout, "SPI (and MRAA) Setup\n");

  LEDSetup();
  fprintf(stdout, "LED Setup\n");

  // Send Init LED from setup
  mraa_gpio_write(cs_c, 1);
  LEDSend();
  mraa_gpio_write(cs_c, 0);
  spi_lcd_or_led = 0;

  LCDSetup();
  fprintf(stdout, "LCD Setup\n");

  button = mraa_gpio_init(33);
  if (button == NULL) {
    fprintf(stderr, "Failed to initialize GPIO %d\n", 33);
    mraa_deinit();
    return -1;
  }

  status = mraa_gpio_dir(button, MRAA_GPIO_IN);
  if (status != MRAA_SUCCESS) {
    puts("Status bad for input");
  }

  status =  mraa_gpio_isr(button, MRAA_GPIO_EDGE_FALLING, &buttonISR, NULL);
  if (status != MRAA_SUCCESS) {
    puts("Status bad for isr");
  }
  
  spi_lcd_or_led = 0;
  pthread_create(&spi_thread, NULL, SPILoop, NULL);
  pthread_create(&playback_thread, NULL, TrackPlay, NULL);

  // Bluetooth Activate!
  ServerStart();
  fprintf(stdout, "Server Started\n");
  
  while (1) {
    sleep(5);
  }

  PlaybackCleanup();
  return 0;
}

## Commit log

2018-01-31 v1 LED_Spin_Speaker model
    [V1_design.blend]
2018-02-04 init blueAppClient threading
2018-02-06 midi box model started
    [Controller_Box.blend]
2018-02-08 MCD box base done
    [Controller_Box.blend]
2018-02-09 first draft mcb laser cut
2018-03-12 BOM init
2018-03-12 init BOM
2018-03-15 NO MOVING PARTS
    [V1_design.blend]
2018-03-15 init new speaker plan
    [1-8inch_TFT_Color_LCD.blend, 1-8inch_TFT_Color_LCD.stl]
2018-03-17 Added LED Speaker Schematicsish
2018-03-18 Pin 30 -> pin 31
2018-03-19 added pcb
    [PCB_Project.PrjPcb, btretro.PrjPcb, btretro_main.SchDoc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]
2018-03-19 added BOM and part numbers for everything
    [PCB_Project.PrjPcb, btretro.PrjPcb, btretro.xlsx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]
2018-03-21 Added fabrication files under project outputs
    [btretro.PrjPcb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]
2018-03-26 added spi class'
2018-03-27 compile error from desktop
    [lcd_tft.c, led.c, led.h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]
2018-03-28 major threading for SPI inplace
2018-03-28 fixed mraa memory leak
    [lcd_tft.c, main.c]
2018-03-28 idk what i changed
    [btretro.PrjPcb, btretro_main.SchDoc]
2018-03-29 laser cut vectors
2018-04-01 working sampler
2018-04-02 updated laser cuts
2018-04-05 updated code to go with board
2018-04-05 first basic LED effects
